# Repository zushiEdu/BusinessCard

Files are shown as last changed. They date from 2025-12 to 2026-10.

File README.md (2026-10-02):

# Business Card

This is my business card.

My business card is a PCB, using the STM32F103C8T6 microcontroller as it's brain.

The STM32 is connected to 6 push buttons and a 12x12 LED matrix. The push buttons and LED matrix are laid out to look like a GameBoy Classic. 

The business card has a collection of common engineering related symbols, values, equations, and footprints on the back.

The STM32 is programmed to simulate John Conway's Game of Life. The push buttons allow you to control the game board and the power of the system.

To toggle edit mode, the user can press A. While the game is not in edit mode, pressing B turns on and off the screen.

The Up/Down/Left/Right buttons move the cursor around when in edit mode. While in edit mode, the cursor will flash and the user can press B to toggle the hovered pixel.

Some cool patterns are printed across the front of the PCB, these are patterns that do cool things in Conway's Game of Life.

The QR code to my portfolio, and some contact info is also on the front of the PCB.

Picture of KiCad PCB view

Picture of actual Business Card Front

Picture of actual Business Card Back

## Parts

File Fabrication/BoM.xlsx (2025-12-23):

Comment | Designator | Footprint | JLCPCB Part #
100nF | C1 C2 C3 C4 | 402 | C1525
4.7uF | C5 | 402 | C23733
LED | D2-145 | 603 | C2286
STM32F103C8T6 | U1 | QFP50P900X900X160-48N | C8734
10K | R1 | 402 | C25744
1000 | R2-7 | 402 | C11702
220 | R8-19 | 402 | C25091
D_Schottky | D1 | D_SOD_323 | C191023

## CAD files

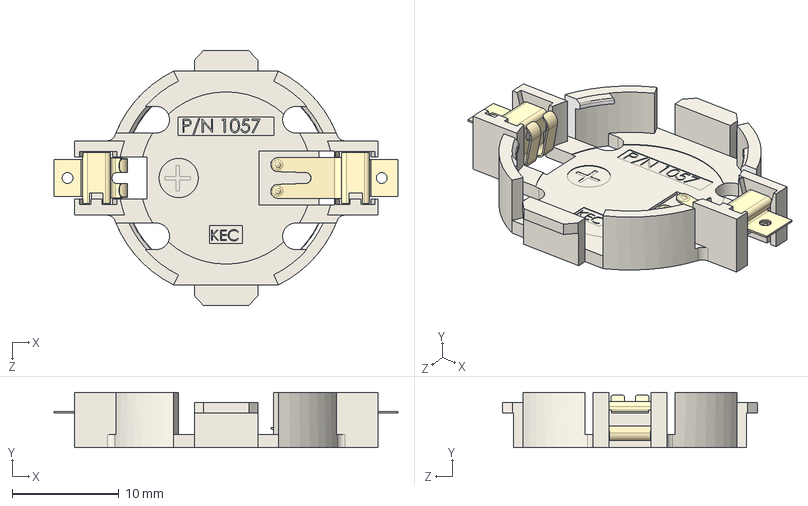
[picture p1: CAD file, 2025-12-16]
Dependencies/KEYSTONE1057/1057--3DModel-STEP-630548.STEP
32.3 x 5.21 x 23.9 mm

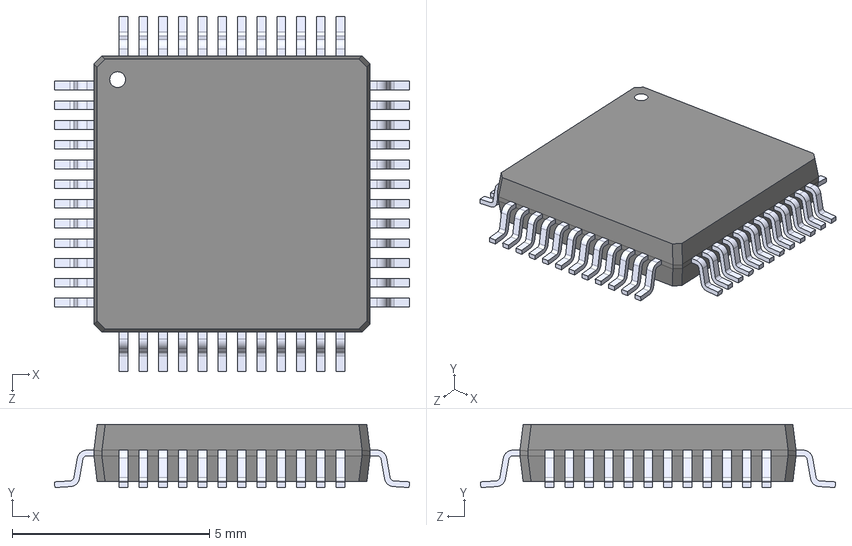
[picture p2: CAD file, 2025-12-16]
Dependencies/STM32F103C8T6/STM32F103C8T6.step
9.00 x 1.60 x 9.00 mm

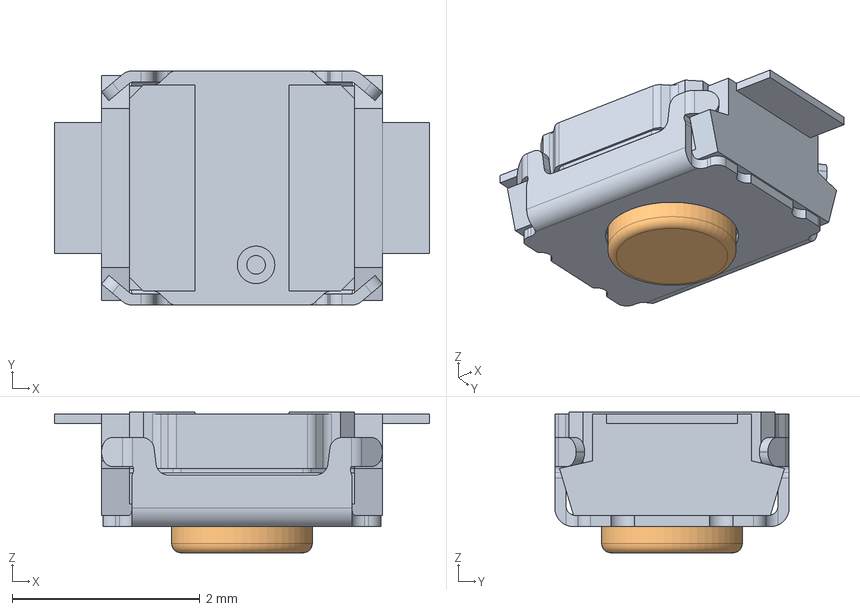
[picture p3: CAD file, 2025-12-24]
Dependencies/TL1015AF160QG/TL1017AAAFxxxQG.stp
4.00 x 2.50 x 1.50 mm

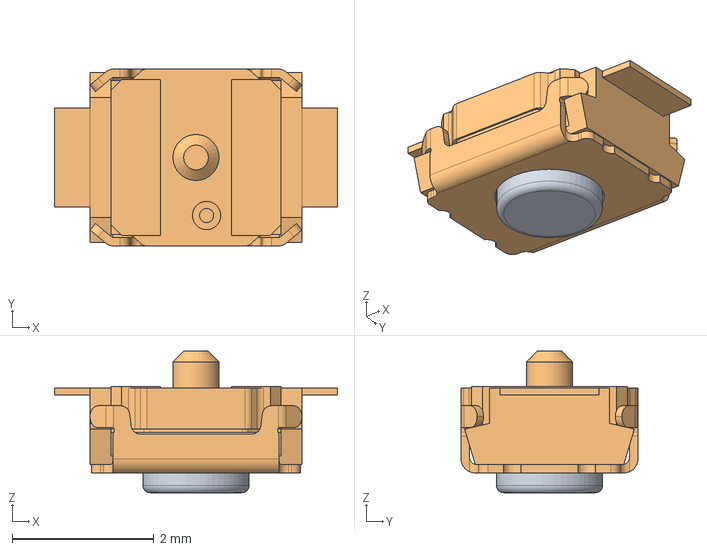
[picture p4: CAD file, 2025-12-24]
Dependencies/TL1015AF160QG/TL1017ABAF160QG.STEP
4.00 x 2.50 x 2.00 mm

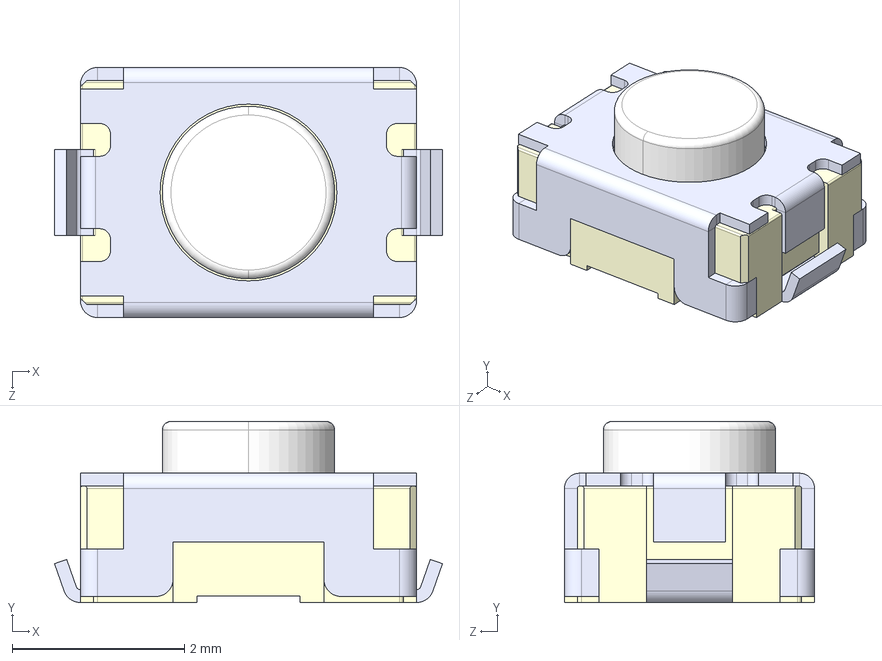
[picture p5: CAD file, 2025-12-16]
Dependencies/TL1015AF160QG/TL1015AF160QG.step
4.50 x 2.10 x 2.90 mm

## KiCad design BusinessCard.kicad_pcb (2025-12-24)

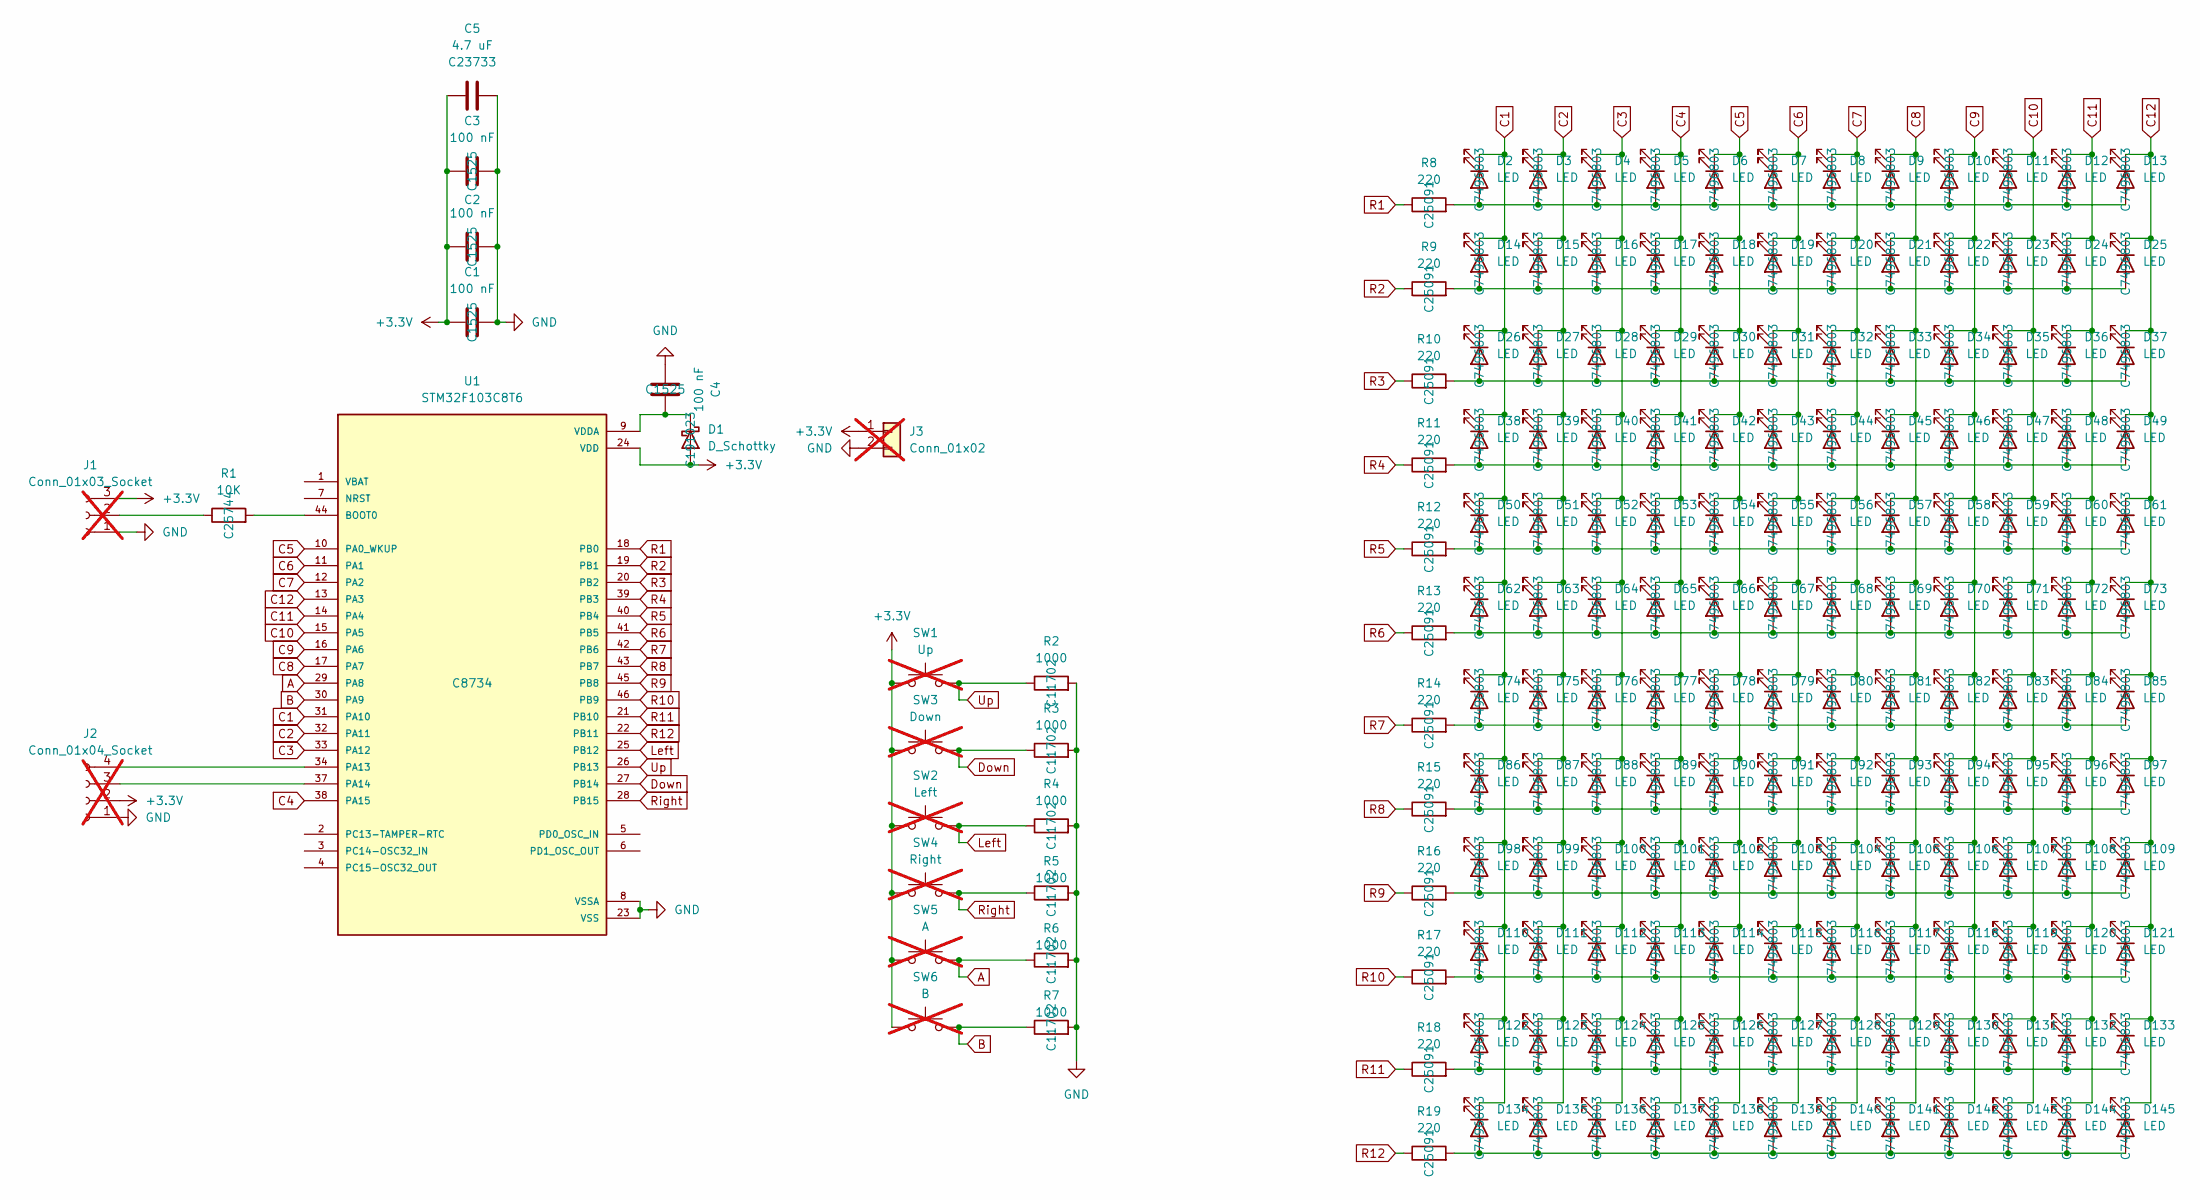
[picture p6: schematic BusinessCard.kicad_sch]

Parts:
C1, C2, C3, C4: 100 nF; C_0402_1005Metric_Pad0.74x0.62mm_HandSolder; LCSC C1525
C5: 4.7 uF; C_0402_1005Metric_Pad0.74x0.62mm_HandSolder; LCSC C23733
D1: D_Schottky; D_SOD-323; LCSC C191023
D2, D3, D4, D5, D6, D7, D8, D9, D10, D11, D12, D13, D14, D15, D16, D17, D18, D19, D20, D21, D22, D23, D24, D25, D26, D27, D28, D29, D30, D31, D32, D33, D34, D35, D36, D37, D38, D39, D40, D41, D42, D43, D44, D45, D46, D47, D48, D49, D50, D51, D52, D53, D54, D55, D56, D57, D58, D59, D60, D61, D62, D63, D64, D65, D66, D67, D68, D69, D70, D71, D72, D73, D74, D75, D76, D77, D78, D79, D80, D81, D82, D83, D84, D85, D86, D87, D88, D89, D90, D91, D92, D93, D94, D95, D96, D97, D98, D99, D100, D101, D102, D103, D104, D105, D106, D107, D108, D109, D110, D111, D112, D113, D114, D115, D116, D117, D118, D119, D120, D121, D122, D123, D124, D125, D126, D127, D128, D129, D130, D131, D132, D133, D134, D135, D136, D137, D138, D139, D140, D141, D142, D143, D144, D145: LED; LED_0603_1608Metric_Notext; LCSC C7496803
J1: Conn_01x03_Socket; RoundSolderPad_1x3_1mm; not fitted
J2: Conn_01x04_Socket; RoundSolderPad_1x4_1mm; not fitted
J3: Conn_01x02; Keystone_1057; not fitted
R1: 10K; R_0402_1005Metric_Pad0.72x0.64mm_HandSolder_Notext; LCSC C25744
R2, R3, R4, R5, R6, R7: 1000; R_0402_1005Metric_Pad0.72x0.64mm_HandSolder_Notext; LCSC C11702
R8, R9, R10, R11, R12, R13, R14, R15, R16, R17, R18, R19: 220; R_0402_1005Metric_Pad0.72x0.64mm_HandSolder_Notext; LCSC C25091
SW1: Up; SW_TL1015AF160QG; not fitted
SW2: Left; SW_TL1015AF160QG; not fitted
SW3: Down; SW_TL1015AF160QG; not fitted
SW4: Right; SW_TL1015AF160QG; not fitted
SW5: A; SW_TL1015AF160QG; not fitted
SW6: B; SW_TL1015AF160QG; not fitted
U1: STM32F103C8T6; QFP50P900X900X160-48N; PARTREV 10; LCSC C8734

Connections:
+3.3V: C1.1, C2.1, C3.1, C5.1, D1.2 (A), J1.3, J2.2, J3.1, SW1.1, SW2.1, SW3.1, SW4.1, SW5.1, SW6.1, U1.24 (VDD), U1.36 (VDD), U1.48 (VDD)
A: R6.1, SW5.2, U1.29 (PA8)
B: R7.1, SW6.2, U1.30 (PA9)
C1: D2.1 (K), D14.1 (K), D26.1 (K), D38.1 (K), D50.1 (K), D62.1 (K), D74.1 (K), D86.1 (K), D98.1 (K), D110.1 (K), D122.1 (K), D134.1 (K), U1.31 (PA10)
C2: D3.1 (K), D15.1 (K), D27.1 (K), D39.1 (K), D51.1 (K), D63.1 (K), D75.1 (K), D87.1 (K), D99.1 (K), D111.1 (K), D123.1 (K), D135.1 (K), U1.32 (PA11)
C3: D4.1 (K), D16.1 (K), D28.1 (K), D40.1 (K), D52.1 (K), D64.1 (K), D76.1 (K), D88.1 (K), D100.1 (K), D112.1 (K), D124.1 (K), D136.1 (K), U1.33 (PA12)
C4: D5.1 (K), D17.1 (K), D29.1 (K), D41.1 (K), D53.1 (K), D65.1 (K), D77.1 (K), D89.1 (K), D101.1 (K), D113.1 (K), D125.1 (K), D137.1 (K), U1.38 (PA15)
C5: D6.1 (K), D18.1 (K), D30.1 (K), D42.1 (K), D54.1 (K), D66.1 (K), D78.1 (K), D90.1 (K), D102.1 (K), D114.1 (K), D126.1 (K), D138.1 (K), U1.10 (PA0_WKUP)
C6: D7.1 (K), D19.1 (K), D31.1 (K), D43.1 (K), D55.1 (K), D67.1 (K), D79.1 (K), D91.1 (K), D103.1 (K), D115.1 (K), D127.1 (K), D139.1 (K), U1.11 (PA1)
C7: D8.1 (K), D20.1 (K), D32.1 (K), D44.1 (K), D56.1 (K), D68.1 (K), D80.1 (K), D92.1 (K), D104.1 (K), D116.1 (K), D128.1 (K), D140.1 (K), U1.12 (PA2)
C8: D9.1 (K), D21.1 (K), D33.1 (K), D45.1 (K), D57.1 (K), D69.1 (K), D81.1 (K), D93.1 (K), D105.1 (K), D117.1 (K), D129.1 (K), D141.1 (K), U1.17 (PA7)
C9: D10.1 (K), D22.1 (K), D34.1 (K), D46.1 (K), D58.1 (K), D70.1 (K), D82.1 (K), D94.1 (K), D106.1 (K), D118.1 (K), D130.1 (K), D142.1 (K), U1.16 (PA6)
C10: D11.1 (K), D23.1 (K), D35.1 (K), D47.1 (K), D59.1 (K), D71.1 (K), D83.1 (K), D95.1 (K), D107.1 (K), D119.1 (K), D131.1 (K), D143.1 (K), U1.15 (PA5)
C11: D12.1 (K), D24.1 (K), D36.1 (K), D48.1 (K), D60.1 (K), D72.1 (K), D84.1 (K), D96.1 (K), D108.1 (K), D120.1 (K), D132.1 (K), D144.1 (K), U1.14 (PA4)
C12: D13.1 (K), D25.1 (K), D37.1 (K), D49.1 (K), D61.1 (K), D73.1 (K), D85.1 (K), D97.1 (K), D109.1 (K), D121.1 (K), D133.1 (K), D145.1 (K), U1.13 (PA3)
Down: R3.1, SW3.2, U1.27 (PB14)
GND: C1.2, C2.2, C3.2, C4.1, C5.2, J1.1, J2.1, J3.2, R2.2, R3.2, R4.2, R5.2, R6.2, R7.2, U1.8 (VSSA), U1.23 (VSS), U1.35 (VSS), U1.47 (VSS)
Left: R4.1, SW2.2, U1.25 (PB12)
unnamed: C4.2, D1.1 (K), U1.9 (VDDA)
unnamed: D2.2 (A), D3.2 (A), D4.2 (A), D5.2 (A), D6.2 (A), D7.2 (A), D8.2 (A), D9.2 (A), D10.2 (A), D11.2 (A), D12.2 (A), D13.2 (A), R8.2
unnamed: D14.2 (A), D15.2 (A), D16.2 (A), D17.2 (A), D18.2 (A), D19.2 (A), D20.2 (A), D21.2 (A), D22.2 (A), D23.2 (A), D24.2 (A), D25.2 (A), R9.2
unnamed: D26.2 (A), D27.2 (A), D28.2 (A), D29.2 (A), D30.2 (A), D31.2 (A), D32.2 (A), D33.2 (A), D34.2 (A), D35.2 (A), D36.2 (A), D37.2 (A), R10.2
unnamed: D38.2 (A), D39.2 (A), D40.2 (A), D41.2 (A), D42.2 (A), D43.2 (A), D44.2 (A), D45.2 (A), D46.2 (A), D47.2 (A), D48.2 (A), D49.2 (A), R11.2
unnamed: D50.2 (A), D51.2 (A), D52.2 (A), D53.2 (A), D54.2 (A), D55.2 (A), D56.2 (A), D57.2 (A), D58.2 (A), D59.2 (A), D60.2 (A), D61.2 (A), R12.2
unnamed: D62.2 (A), D63.2 (A), D64.2 (A), D65.2 (A), D66.2 (A), D67.2 (A), D68.2 (A), D69.2 (A), D70.2 (A), D71.2 (A), D72.2 (A), D73.2 (A), R13.2
unnamed: D74.2 (A), D75.2 (A), D76.2 (A), D77.2 (A), D78.2 (A), D79.2 (A), D80.2 (A), D81.2 (A), D82.2 (A), D83.2 (A), D84.2 (A), D85.2 (A), R14.2
unnamed: D86.2 (A), D87.2 (A), D88.2 (A), D89.2 (A), D90.2 (A), D91.2 (A), D92.2 (A), D93.2 (A), D94.2 (A), D95.2 (A), D96.2 (A), D97.2 (A), R15.2
unnamed: D98.2 (A), D99.2 (A), D100.2 (A), D101.2 (A), D102.2 (A), D103.2 (A), D104.2 (A), D105.2 (A), D106.2 (A), D107.2 (A), D108.2 (A), D109.2 (A), R16.2
unnamed: D110.2 (A), D111.2 (A), D112.2 (A), D113.2 (A), D114.2 (A), D115.2 (A), D116.2 (A), D117.2 (A), D118.2 (A), D119.2 (A), D120.2 (A), D121.2 (A), R17.2
unnamed: D122.2 (A), D123.2 (A), D124.2 (A), D125.2 (A), D126.2 (A), D127.2 (A), D128.2 (A), D129.2 (A), D130.2 (A), D131.2 (A), D132.2 (A), D133.2 (A), R18.2
unnamed: D134.2 (A), D135.2 (A), D136.2 (A), D137.2 (A), D138.2 (A), D139.2 (A), D140.2 (A), D141.2 (A), D142.2 (A), D143.2 (A), D144.2 (A), D145.2 (A), R19.2
unnamed: J1.2, R1.1
unnamed: J2.3, U1.37 (PA14)
unnamed: J2.4, U1.34 (PA13)
unnamed: R1.2, U1.44 (BOOT0)
R1: R8.1, U1.18 (PB0)
R2: R9.1, U1.19 (PB1)
R3: R10.1, U1.20 (PB2)
R4: R11.1, U1.39 (PB3)
R5: R12.1, U1.40 (PB4)
R6: R13.1, U1.41 (PB5)
R7: R14.1, U1.42 (PB6)
R8: R15.1, U1.43 (PB7)
R9: R16.1, U1.45 (PB8)
R10: R17.1, U1.46 (PB9)
R11: R18.1, U1.21 (PB10)
R12: R19.1, U1.22 (PB11)
Right: R5.1, SW4.2, U1.28 (PB15)
Up: R2.1, SW1.2, U1.26 (PB13)

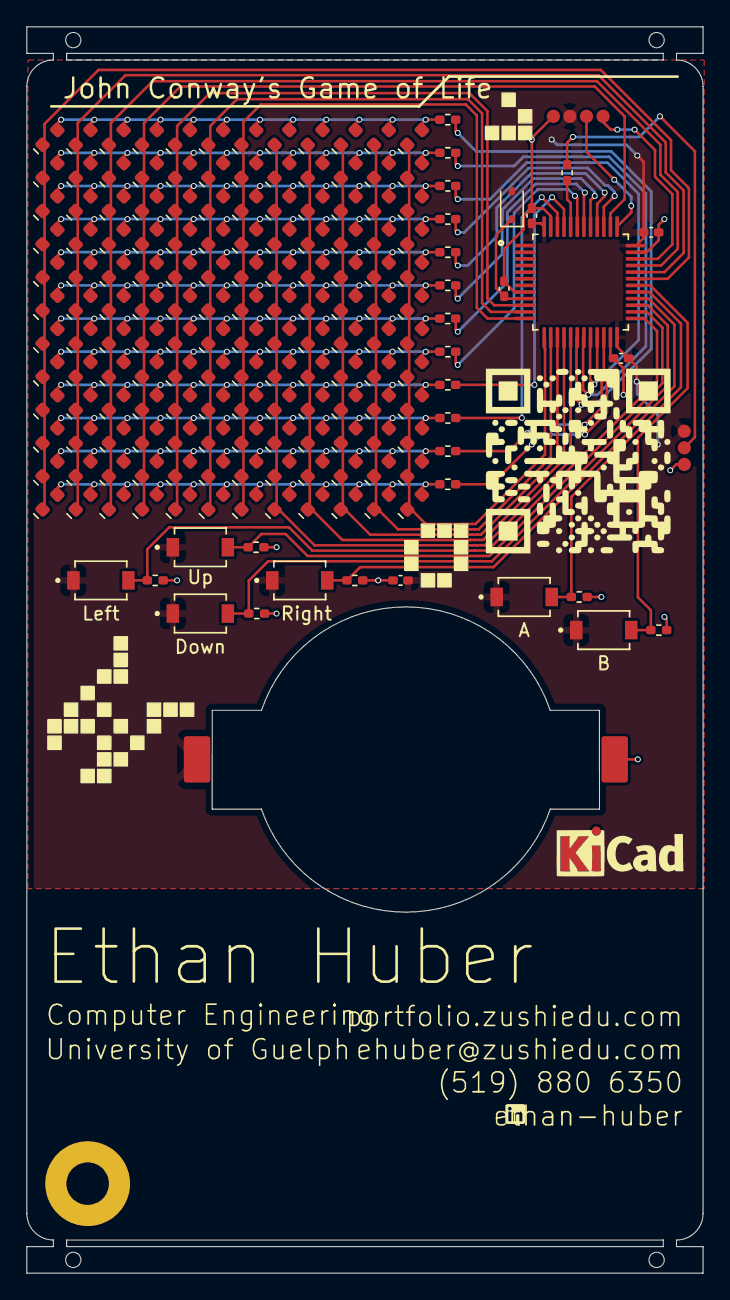
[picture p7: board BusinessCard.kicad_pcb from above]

Board: 2 copper layers, 51.0 x 94.0 mm, 179 parts (0 on the bottom side), 49 nets.

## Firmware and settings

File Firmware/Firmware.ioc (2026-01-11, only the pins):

Mcu.UserName=STM32F103C8Tx
PA0-WKUP.Signal=GPIO_Output
PA1.Signal=GPIO_Output
PA10.Signal=GPIO_Output
PA11.Signal=GPIO_Output
PA12.Signal=GPIO_Output
PA13.Signal=SYS_JTMS-SWDIO
PA14.Signal=SYS_JTCK-SWCLK
PA15.Signal=GPIO_Output
PA2.Signal=GPIO_Output
PA3.Signal=GPIO_Output
PA4.Signal=GPIO_Output
PA5.Signal=GPIO_Output
PA6.Signal=GPIO_Output
PA7.Signal=GPIO_Output
PA8.Signal=GPIO_Input
PA9.Signal=GPIO_Input
PB0.Signal=GPIO_Output
PB1.Signal=GPIO_Output
PB10.Signal=GPIO_Output
PB11.Signal=GPIO_Output
PB12.Signal=GPIO_Input
PB13.Signal=GPIO_Input
PB14.Signal=GPIO_Input
PB15.Signal=GPIO_Input
PB2.Signal=GPIO_Output
PB3.Signal=GPIO_Output
PB4.Signal=GPIO_Output
PB5.Signal=GPIO_Output
PB6.Signal=GPIO_Output
PB7.Signal=GPIO_Output
PB8.Signal=GPIO_Output
PB9.Signal=GPIO_Output

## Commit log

2025-12-16 First Sync
    [1057--3DModel-STEP-630548.STEP, BusinessCard.kicad_pcb, BusinessCard.kicad_sch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]
2025-12-16 Add various SMD resistor footprints and mounting hole
    Added new SMD resistor footprints (0201, 0402, 0805, 2010, 2512) and a 3.2mm M3 mounting hole to the PCB layout. Updated backup files and removed an old autosave.
    [BusinessCard.kicad_pcb]
2025-12-19 Add logo footprint and update TQFP-32 package
    Added a new 'LOGO' footprint to the front copper layer and replaced the 'R_0201_0603Metric' resistor footprint with a 'TQFP-32_7x7mm_P0.8mm' package on the back copper layer. Updated backup files and made minor adjustments to mounting hole and property attributes.
    [BusinessCard.kicad_pcb]
2025-12-20 Rearranged back and added KiCad logo
    - Rearranged back to avoid via collision
    - Added KiCad logo
    - Moved some via's for cleanliness
    - Moved keychain hole label position
    [BusinessCard-B_Cu.gbl, BusinessCard-B_Mask.gbs, BusinessCard-B_Paste.gbp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]
2025-12-22 Fabrication edits
    - Added JLCPCB component part numbers
    [BoM.xlsx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]
2025-12-23 Switched LED footprint and fixed row traces
    - Switched LED footprints from 0402 to 0603 to reduce assembly cost
    - Added back row traces that were accidentally removed in an earlier commit
    [BoM.xlsx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]
2025-12-24 Changed model of buttons to cheaper version
    [BusinessCard.kicad_pcb, TL1017AAAFxxxQG.stp, TL1017ABAF160QG.STEP]
2026-01-11 Static oscillator Conway's Game of Life Firmware
    [Firmware.ioc]
2026-01-11 Add project details for business card PCB
    Added detailed description of the business card project, including its features and functionality.
2026-01-11 Added board editing
